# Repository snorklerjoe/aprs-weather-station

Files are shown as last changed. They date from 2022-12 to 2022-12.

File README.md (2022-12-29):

# aprs-weather-station
An APRS weather station with a transmitter designed from scratch

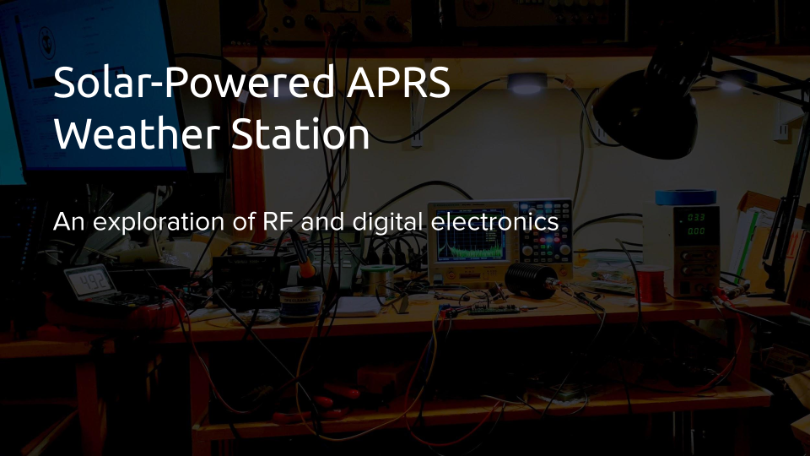
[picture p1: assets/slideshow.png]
Link to slideshow with more info (https://docs.google.com/presentation/d/e/2PACX-1vTTjzmcnAMqO2CPDlmQrg4AF5uw97dXVN1kHOskOywPoeaysDxAKATVa35npatWT-IwA0Ih-Vha_gMK/pub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)

_(Slideshow with more info)_

For more information, see my [blog](https://www.hosticlefifer.com/blog/?show=14)!

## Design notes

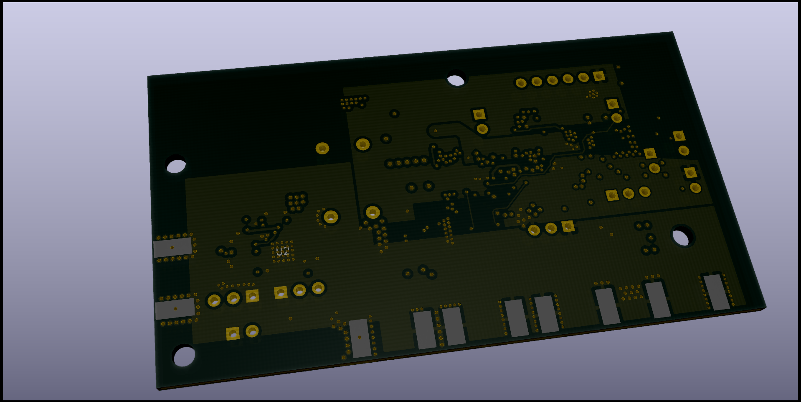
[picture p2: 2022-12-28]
hardware/radio/radio_back.png

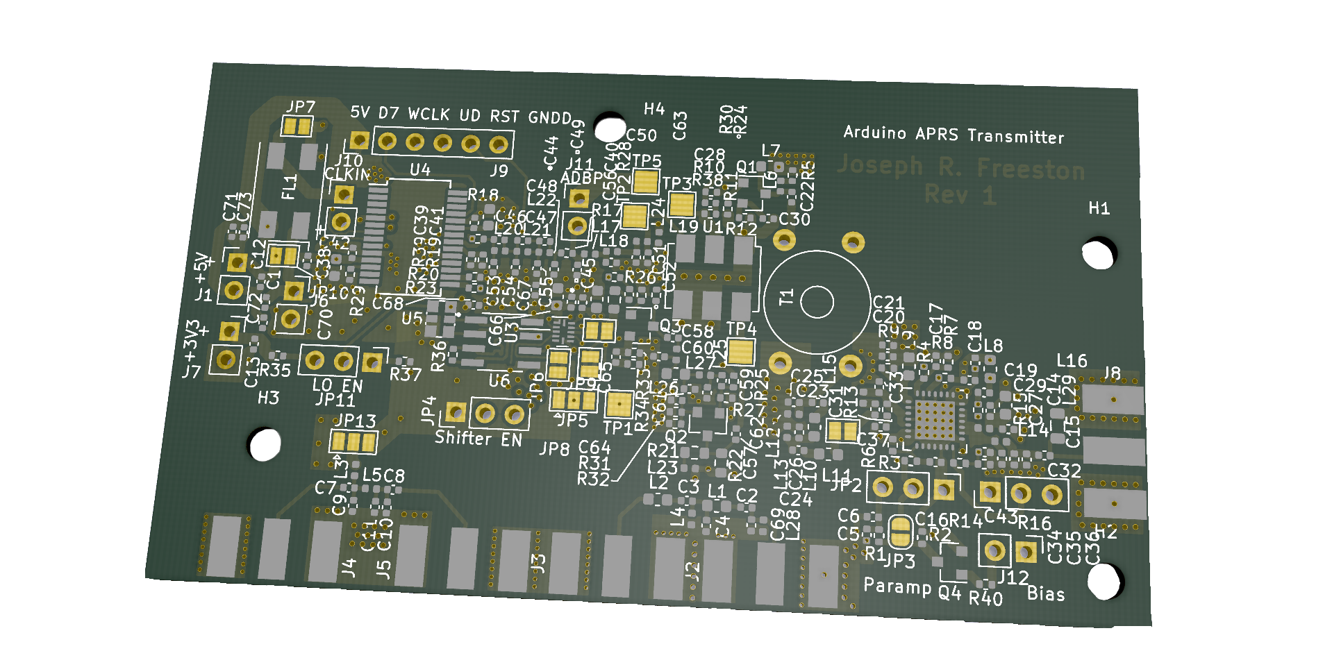
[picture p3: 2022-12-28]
hardware/radio/radio.png

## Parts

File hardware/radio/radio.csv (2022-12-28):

Source: | /home/joseph/projects/weather-station/radio/radio.sch
Date: | Wed 24 Nov 2021 07:50:49 PM EST
Tool: | Eeschema 5.1.12-84ad8e8a86~92~ubuntu20.04.1
Generator: | /usr/share/kicad/plugins/bom_csv_grouped_by_value.py
Component Count: | 165
Individual Components:
Item | Qty | Reference(s) | Value | LibPart | Footprint | Datasheet | Category | DK_Datasheet_Link | DK_Detail_Page | Description | Digi-Key_PN | Family | MPN | Manufacturer | Status
 |  | C1 | 10u | Device:C_Small |  | ~
 |  | C2 | 1p | Device:C_Small |  | ~
 |  | C3 | 1p | Device:C_Small |  | ~
 |  | C4 | 510p | Device:C_Small |  | ~
 |  | C5 | 1u | Device:C_Small |  | ~
 |  | C6 | 470p | Device:C_Small |  | ~
 |  | C7 | 2.5n | Device:C |  | ~
 |  | C8 | 470p | Device:C_Small |  | ~
 |  | C9 | 12p | Device:C_Small |  | ~
 |  | C10 | 56p | Device:C_Small |  | ~
 |  | C11 | 5.6p | Device:C_Small |  | ~
 |  | C12 | 10u | Device:C_Small |  | ~
 |  | C13 | 10u | Device:C_Small |  | ~
 |  | C14 | 4.7u | Device:C_Small |  | ~
 |  | C15 | 470p | Device:C_Small |  | ~
 |  | C16 | 10n | Device:C |  | ~
 |  | C17 | 10n | Device:C |  | ~
 |  | C18 | 470p | Device:C_Small |  | ~
 |  | C19 | 1u | Device:C_Small |  | ~
 |  | C20 | 1u | Device:C_Small |  | ~
 |  | C21 | 470p | Device:C_Small |  | ~
 |  | C22 | 2.5n | Device:C |  | ~
 |  | C23 | 1p | Device:C_Small |  | ~
 |  | C24 | 1p | Device:C_Small |  | ~
 |  | C25 | 510p | Device:C_Small |  | ~
 |  | C26 | 510p | Device:C_Small |  | ~
 |  | C27 | 1u | Device:C_Small |  | ~
 |  | C28 | 2.5n | Device:C |  | ~
 |  | C29 | C_Small | Device:C_Small |  | ~
 |  | C30 | 1n | Device:C_Small |  | ~
 |  | C31 | 470pF | Device:C_Small |  | ~
 |  | C32 | 470p | Device:C_Small |  | ~
 |  | C33 | 3.3pF | Device:C_Small |  | ~
 |  | C34 | 12p | Device:C_Small |  | ~
 |  | C35 | 56p | Device:C_Small |  | ~
 |  | C36 | 5.6p | Device:C_Small |  | ~
 |  | C37 | 1nF | Device:C_Small |  | ~
 |  | C38 | 10u | Device:C_Small |  | ~
 |  | C39 | 10u | Device:C_Small |  | ~
 |  | C40 | 10u | Device:C_Small |  | ~
 |  | C41 | 0.1u | Device:C_Small |  | ~
 |  | C42 | 0.1u | Device:C_Small |  | ~
 |  | C43 | 100p | Device:C |  | ~
 |  | C44 | 0.1u | Device:C_Small |  | ~
 |  | C45 | 0.1u | Device:C_Small |  | ~
 |  | C46 | 1p | Device:C_Small |  | ~
 |  | C47 | 5.6p | Device:C_Small |  | ~
 |  | C48 | 4.7p | Device:C_Small |  | ~
 |  | C49 | 1.5n | Device:C_Small |  | ~
 |  | C50 | 2n | Device:C_Small |  | ~
 |  | C51 | 2n | Device:C_Small |  | ~
 |  | C52 | 2n | Device:C_Small |  | ~
 |  | C53 | 22p | Device:C_Small |  | ~
 |  | C54 | 33p | Device:C_Small |  | ~
 |  | C55 | 22p | Device:C_Small |  | ~
 |  | C56 | 22p | Device:C_Small |  | ~
 |  | C57 | 2.5n | Device:C |  | ~
 |  | C58 | 2.5n | Device:C |  | ~
 |  | C59 | 2.5n | Device:C |  | ~
 |  | C60 | 36p | Device:C_Small |  | ~
 |  | C61 | 47p | Device:C_Small |  | ~
 |  | C62 | 13p | Device:C_Small |  | ~
 |  | C63 | 2.5n | Device:C |  | ~
 |  | C64 | 2.5n | Device:C_Small |  | ~
 |  | C65 | 100p | Device:C_Small |  | ~
 |  | C66 | 10u | Device:C_Small |  | ~
 |  | C67 | 0.1uF | Device:C_Small |  | ~
 |  | C68 | 0.1uF | Device:C_Small |  | ~
 |  | FL1 | EMI_Filter_CommonMode | Device:EMI_Filter_CommonMode |  | ~
 |  | J1 | +5VD | Connector:Conn_01x02_Male |  | ~
 |  | J2 | in | dk_Coaxial-Connectors-RF:142-0701-801 | digikey-footprints:RF_SMA_BoardEdge_142-0701-801 | http://www.belfuse.com/resources/Johnson/drawings/dr-1420701801.pdf | Connectors, Interconnects | http://www.belfuse.com/resources/Johnson/drawings/dr-1420701801.pdf | /product-detail/en/cinch-connectivity-solutions-johnson/142-0701-801/J502-ND/35280 | CONN SMA JACK STR 50OHM EDGE MNT | J502-ND | Coaxial Connectors (RF) | 142-0701-801 | Cinch Connectivity Solutions Johnson | Active
 |  | J3 | out | dk_Coaxial-Connectors-RF:142-0701-801 | digikey-footprints:RF_SMA_BoardEdge_142-0701-801 | http://www.belfuse.com/resources/Johnson/drawings/dr-1420701801.pdf | Connectors, Interconnects | http://www.belfuse.com/resources/Johnson/drawings/dr-1420701801.pdf | /product-detail/en/cinch-connectivity-solutions-johnson/142-0701-801/J502-ND/35280 | CONN SMA JACK STR 50OHM EDGE MNT | J502-ND | Coaxial Connectors (RF) | 142-0701-801 | Cinch Connectivity Solutions Johnson | Active
 |  | J4 | in | dk_Coaxial-Connectors-RF:142-0701-801 | digikey-footprints:RF_SMA_BoardEdge_142-0701-801 | http://www.belfuse.com/resources/Johnson/drawings/dr-1420701801.pdf | Connectors, Interconnects | http://www.belfuse.com/resources/Johnson/drawings/dr-1420701801.pdf | /product-detail/en/cinch-connectivity-solutions-johnson/142-0701-801/J502-ND/35280 | CONN SMA JACK STR 50OHM EDGE MNT | J502-ND | Coaxial Connectors (RF) | 142-0701-801 | Cinch Connectivity Solutions Johnson | Active
 |  | J5 | out | dk_Coaxial-Connectors-RF:142-0701-801 | digikey-footprints:RF_SMA_BoardEdge_142-0701-801 | http://www.belfuse.com/resources/Johnson/drawings/dr-1420701801.pdf | Connectors, Interconnects | http://www.belfuse.com/resources/Johnson/drawings/dr-1420701801.pdf | /product-detail/en/cinch-connectivity-solutions-johnson/142-0701-801/J502-ND/35280 | CONN SMA JACK STR 50OHM EDGE MNT | J502-ND | Coaxial Connectors (RF) | 142-0701-801 | Cinch Connectivity Solutions Johnson | Active
 |  | J6 | +5VA | Connector:Conn_01x02_Male |  | ~
 |  | J7 | +3VA | Connector:Conn_01x02_Male |  | ~
 |  | J8 | Antenna | dk_Coaxial-Connectors-RF:142-0701-801 | digikey-footprints:RF_SMA_BoardEdge_142-0701-801 | http://www.belfuse.com/resources/Johnson/drawings/dr-1420701801.pdf | Connectors, Interconnects | http://www.belfuse.com/resources/Johnson/drawings/dr-1420701801.pdf | /product-detail/en/cinch-connectivity-solutions-johnson/142-0701-801/J502-ND/35280 | CONN SMA JACK STR 50OHM EDGE MNT | J502-ND | Coaxial Connectors (RF) | 142-0701-801 | Cinch Connectivity Solutions Johnson | Active
 |  | J9 | FREQ CTRL | Connector:Conn_01x06_Male |  | ~
 |  | J10 | CLK_125MHz | Connector:Conn_01x02_Male |  | ~
 |  | J11 | 50 Ohm IF IN | Connector:Conn_01x02_Male |  | ~
 |  | JP1 | Vbias | Device:Jumper_NC_Dual |  | ~
 |  | JP2 | Vparamp | Device:Jumper_NC_Dual |  | ~
 |  | JP3 | paramp en | Jumper:SolderJumper_2_Open |  | ~
 |  | JP4 | DDS Clock EN | Device:Jumper_NC_Dual |  | ~
 |  | JP5 | Shift LO | Jumper:SolderJumper_3_Bridged12 |  | ~
 |  | JP6 | A3 | Jumper:SolderJumper_2_Bridged |  | ~
 |  | JP7 | choke bp | Jumper:SolderJumper_2_Open |  | ~
 |  | JP8 | 5V LO | Jumper:SolderJumper_2_Open |  | ~
 |  | JP9 | 3V LO | Jumper:SolderJumper_2_Bridged |  | ~
 |  | JP10 | choke bp | Jumper:SolderJumper_2_Open |  | ~
 |  | JP11 | Jumper_NC_Dual | Device:Jumper_NC_Dual |  | ~
 |  | L1 | 1.2u | Device:L |  | ~
 |  | L2 | 1.2u | Device:L |  | ~
 |  | L3 | 19n | Device:L |  | ~
 |  | L4 | 2.4n | Device:L |  | ~
 |  | L5 | 12n | Device:L |  | ~
 |  | L6 | 0.1u | Device:L |  | 0630CS
 |  | L7 | 5u | Device:L |  | 0630CS
 |  | L8 | 56n | Device:L |  | ~
 |  | L9 | 56n | Device:L |  | ~
 |  | L10 | 1.2u | Device:L |  | ~
 |  | L11 | 1.2u | Device:L |  | ~
 |  | L12 | 2.4n | Device:L |  | ~
 |  | L13 | 2.4n | Device:L |  | ~
 |  | L14 | 19n | Device:L |  | ~
 |  | L15 | 150nH | Device:L |  | 0630CS
 |  | L16 | 12n | Device:L |  | ~
 |  | L17 | 120n | Device:L |  | ~
 |  | L18 | 130n | Device:L |  | ~
 |  | L19 | 120n | Device:L |  | ~
 |  | L20 | 470n | Device:L |  | ~
 |  | L21 | 390n | Device:L |  | ~
 |  | L22 | 390n | Device:L |  | ~
 |  | L23 | 10u | Device:L |  | ~
 |  | L24 | 10u | Device:L |  | ~
 |  | L25 | 33n | Device:L |  | ~
 |  | L26 | 123n | Device:L |  | ~
 |  | L27 | 90n | Device:L |  | ~
 |  | Q1 | MMBTH10 | Device:Q_NPN_BEC |  | ~
 |  | Q2 | 2N2222 | Device:Q_NPN_BEC |  | ~
 |  | Q3 | 2N2222 | Device:Q_NPN_BEC |  | ~
 |  | R1 | 1k | Device:R |  | ~
 |  | R2 | 1k | Device:R |  | ~
 |  | R3 | 68k | Device:R |  | ~
 |  | R4 | 68k | Device:R |  | ~
 |  | R5 | 51 | Device:R |  | ~
 |  | R6 | 68k | Device:R |  | ~
 |  | R7 | 47k | Device:R |  | ~
 |  | R8 | R | Device:R |  | ~
 |  | R9 | R | Device:R |  | ~
 |  | R10 | 470 | Device:R |  | ~
 |  | R11 | 510 | Device:R |  | ~
 |  | R12 | 68 | Device:R |  | ~
 |  | R13 | 680 | Device:R |  | ~
 |  | R14 | 100k | Device:R |  | ~
 |  | R15 | 51 | Device:R |  | ~
 |  | R16 | 39k | Device:R |  | ~
 |  | R17 | 0 | Device:R |  | ~
 |  | R18 | 50 | Device:R |  | ~
 |  | R19 | 25 | Device:R |  | ~
 |  | R20 | 1k | Device:R |  | ~
 |  | R21 | 30 | Device:R |  | ~
 |  | R22 | 75 | Device:R |  | ~
 |  | R23 | 1k | Device:R |  | ~
 |  | R24 | 150 | Device:R |  | ~
 |  | R25 | 1.2k | Device:R |  | ~
 |  | R26 | 2k | Device:R |  | ~
 |  | R27 | 1.2k | Device:R |  | ~
 |  | R28 | 75 | Device:R |  | ~
 |  | R29 | 3.9k | Device:R |  | ~
 |  | R30 | 1.2k | Device:R |  | ~
 |  | R31 | 47 | Device:R |  | ~
 |  | R32 | 47 | Device:R |  | ~
 |  | R33 | 100 | Device:R |  | ~
 |  | R34 | 10 | Device:R |  | ~
 |  | R35 | 1k | Device:R |  | ~
 |  | R36 | 100 | Device:R |  | ~
 |  | R37 | 1k | Device:R |  | ~
 |  | T1 | Transformer_1P_1S | Device:Transformer_1P_1S |  | ~
 |  | U1 | ADE-11X+ | dk_RF-Demodulators:ADE-11X+ | RF_Mini-Circuits:Mini-Circuits_CD542_LandPatternPL-052 | www.minicircuits.com/pdfs/ADE-6.pdf
 |  | U2 | CMX901 | dk_RF-Amplifiers:CMX901 | Home:QFN-28_EP_5x5_Pitch0.5mm | CMX901QT8
 |  | U3 | TXU0304RUTR | dk_Logic-Translators-Level-Shifters:TXU0304RUTR | Package_DFN_QFN:Texas_R_PUQFN-N12 | http://www.ti.com/lit/ds/symlink/txu0104.pdf
 |  | U4 | AD9850 | Interface:AD9850 | Package_SO:SSOP-28_5.3x10.2mm_P0.65mm | https://www.analog.com/media/en/technical-documentation/data-sheets/AD9850.pdf
 |  | U5 | SiT9365AC-2B1-33E | dk_Oscillators:SiT9365AC-2B1-33E | Home:POD-038-PQFD-006-C03225
 |  | U6 | DS90LV028ATM | DS90LV028ATM:DS90LV028ATM | SOIC127P599X175-8N
Collated Components:
Item | Qty | Reference(s) | Value | LibPart | Footprint | Datasheet | Category | DK_Datasheet_Link | DK_Detail_Page | Description | Digi-Key_PN | Family | MPN | Manufacturer | Status
1 | 7 | C1, C12, C13, C38, C39, C40, C66 | 10u | Device:C_Small |  | ~
2 | 5 | C2, C3, C23, C24, C46 | 1p | Device:C_Small |  | ~
3 | 3 | C4, C25, C26 | 510p | Device:C_Small |  | ~
4 | 4 | C5, C19, C20, C27 | 1u | Device:C_Small |  | ~
5 | 6 | C6, C8, C15, C18, C21, C32 | 470p | Device:C_Small |  | ~
6 | 7 | C7, C22, C28, C57, C58, C59, C63 | 2.5n | Device:C |  | ~
7 | 2 | C9, C34 | 12p | Device:C_Small |  | ~
8 | 2 | C10, C35 | 56p | Device:C_Small |  | ~
9 | 3 | C11, C36, C47 | 5.6p | Device:C_Small |  | ~
10 | 1 | C14 | 4.7u | Device:C_Small |  | ~
11 | 2 | C16, C17 | 10n | Device:C |  | ~
12 | 1 | C29 | C_Small | Device:C_Small |  | ~
13 | 1 | C30 | 1n | Device:C_Small |  | ~
14 | 1 | C31 | 470pF | Device:C_Small |  | ~
15 | 1 | C33 | 3.3pF | Device:C_Small |  | ~
16 | 1 | C37 | 1nF | Device:C_Small |  | ~
17 | 4 | C41, C42, C44, C45 | 0.1u | Device:C_Small |  | ~
18 | 1 | C43 | 100p | Device:C |  | ~
19 | 1 | C48 | 4.7p | Device:C_Small |  | ~
20 | 1 | C49 | 1.5n | Device:C_Small |  | ~
21 | 3 | C50, C51, C52 | 2n | Device:C_Small |  | ~
22 | 3 | C53, C55, C56 | 22p | Device:C_Small |  | ~
23 | 1 | C54 | 33p | Device:C_Small |  | ~
24 | 1 | C60 | 36p | Device:C_Small |  | ~
25 | 1 | C61 | 47p | Device:C_Small |  | ~
26 | 1 | C62 | 13p | Device:C_Small |  | ~
27 | 1 | C64 | 2.5n | Device:C_Small |  | ~
28 | 1 | C65 | 100p | Device:C_Small |  | ~
29 | 2 | C67, C68 | 0.1uF | Device:C_Small |  | ~
30 | 1 | FL1 | EMI_Filter_CommonMode | Device:EMI_Filter_CommonMode |  | ~
31 | 1 | J1 | +5VD | Connector:Conn_01x02_Male |  | ~
32 | 2 | J2, J4 | in | dk_Coaxial-Connectors-RF:142-0701-801 | digikey-footprints:RF_SMA_BoardEdge_142-0701-801 | http://www.belfuse.com/resources/Johnson/drawings/dr-1420701801.pdf | Connectors, Interconnects | http://www.belfuse.com/resources/Johnson/drawings/dr-1420701801.pdf | /product-detail/en/cinch-connectivity-solutions-johnson/142-0701-801/J502-ND/35280 | CONN SMA JACK STR 50OHM EDGE MNT | J502-ND | Coaxial Connectors (RF) | 142-0701-801 | Cinch Connectivity Solutions Johnson | Active
33 | 2 | J3, J5 | out | dk_Coaxial-Connectors-RF:142-0701-801 | digikey-footprints:RF_SMA_BoardEdge_142-0701-801 | http://www.belfuse.com/resources/Johnson/drawings/dr-1420701801.pdf | Connectors, Interconnects | http://www.belfuse.com/resources/Johnson/drawings/dr-1420701801.pdf | /product-detail/en/cinch-connectivity-solutions-johnson/142-0701-801/J502-ND/35280 | CONN SMA JACK STR 50OHM EDGE MNT | J502-ND | Coaxial Connectors (RF) | 142-0701-801 | Cinch Connectivity Solutions Johnson | Active
34 | 1 | J6 | +5VA | Connector:Conn_01x02_Male |  | ~
35 | 1 | J7 | +3VA | Connector:Conn_01x02_Male |  | ~
36 | 1 | J8 | Antenna | dk_Coaxial-Connectors-RF:142-0701-801 | digikey-footprints:RF_SMA_BoardEdge_142-0701-801 | http://www.belfuse.com/resources/Johnson/drawings/dr-1420701801.pdf | Connectors, Interconnects | http://www.belfuse.com/resources/Johnson/drawings/dr-1420701801.pdf | /product-detail/en/cinch-connectivity-solutions-johnson/142-0701-801/J502-ND/35280 | CONN SMA JACK STR 50OHM EDGE MNT | J502-ND | Coaxial Connectors (RF) | 142-0701-801 | Cinch Connectivity Solutions Johnson | Active
37 | 1 | J9 | FREQ CTRL | Connector:Conn_01x06_Male |  | ~
38 | 1 | J10 | CLK_125MHz | Connector:Conn_01x02_Male |  | ~
39 | 1 | J11 | 50 Ohm IF IN | Connector:Conn_01x02_Male |  | ~
40 | 1 | JP1 | Vbias | Device:Jumper_NC_Dual |  | ~
41 | 1 | JP2 | Vparamp | Device:Jumper_NC_Dual |  | ~
42 | 1 | JP3 | paramp en | Jumper:SolderJumper_2_Open |  | ~
43 | 1 | JP4 | DDS Clock EN | Device:Jumper_NC_Dual |  | ~
44 | 1 | JP5 | Shift LO | Jumper:SolderJumper_3_Bridged12 |  | ~
45 | 1 | JP6 | A3 | Jumper:SolderJumper_2_Bridged |  | ~
46 | 2 | JP7, JP10 | choke bp | Jumper:SolderJumper_2_Open |  | ~
47 | 1 | JP8 | 5V LO | Jumper:SolderJumper_2_Open |  | ~
48 | 1 | JP9 | 3V LO | Jumper:SolderJumper_2_Bridged |  | ~
49 | 1 | JP11 | Jumper_NC_Dual | Device:Jumper_NC_Dual |  | ~
50 | 4 | L1, L2, L10, L11 | 1.2u | Device:L |  | ~
51 | 2 | L3, L14 | 19n | Device:L |  | ~
52 | 3 | L4, L12, L13 | 2.4n | Device:L |  | ~
53 | 2 | L5, L16 | 12n | Device:L |  | ~
54 | 1 | L6 | 0.1u | Device:L |  | 0630CS
55 | 1 | L7 | 5u | Device:L |  | 0630CS
56 | 2 | L8, L9 | 56n | Device:L |  | ~
57 | 1 | L15 | 150nH | Device:L |  | 0630CS
58 | 2 | L17, L19 | 120n | Device:L |  | ~
59 | 1 | L18 | 130n | Device:L |  | ~
60 | 1 | L20 | 470n | Device:L |  | ~
61 | 2 | L21, L22 | 390n | Device:L |  | ~
62 | 2 | L23, L24 | 10u | Device:L |  | ~
63 | 1 | L25 | 33n | Device:L |  | ~
64 | 1 | L26 | 123n | Device:L |  | ~
65 | 1 | L27 | 90n | Device:L |  | ~
66 | 1 | Q1 | MMBTH10 | Device:Q_NPN_BEC |  | ~
67 | 2 | Q2, Q3 | 2N2222 | Device:Q_NPN_BEC |  | ~
68 | 6 | R1, R2, R20, R23, R35, R37 | 1k | Device:R |  | ~
69 | 3 | R3, R4, R6 | 68k | Device:R |  | ~
70 | 2 | R5, R15 | 51 | Device:R |  | ~
71 | 1 | R7 | 47k | Device:R |  | ~
72 | 2 | R8, R9 | R | Device:R |  | ~
73 | 1 | R10 | 470 | Device:R |  | ~
74 | 1 | R11 | 510 | Device:R |  | ~
75 | 1 | R12 | 68 | Device:R |  | ~
76 | 1 | R13 | 680 | Device:R |  | ~
77 | 1 | R14 | 100k | Device:R |  | ~
78 | 1 | R16 | 39k | Device:R |  | ~
79 | 1 | R17 | 0 | Device:R |  | ~
80 | 1 | R18 | 50 | Device:R |  | ~
81 | 1 | R19 | 25 | Device:R |  | ~
82 | 1 | R21 | 30 | Device:R |  | ~
83 | 2 | R22, R28 | 75 | Device:R |  | ~
84 | 1 | R24 | 150 | Device:R |  | ~
85 | 3 | R25, R27, R30 | 1.2k | Device:R |  | ~
86 | 1 | R26 | 2k | Device:R |  | ~
87 | 1 | R29 | 3.9k | Device:R |  | ~
88 | 2 | R31, R32 | 47 | Device:R |  | ~
89 | 2 | R33, R36 | 100 | Device:R |  | ~
90 | 1 | R34 | 10 | Device:R |  | ~
91 | 1 | T1 | Transformer_1P_1S | Device:Transformer_1P_1S |  | ~
92 | 1 | U1 | ADE-11X+ | dk_RF-Demodulators:ADE-11X+ | RF_Mini-Circuits:Mini-Circuits_CD542_LandPatternPL-052 | www.minicircuits.com/pdfs/ADE-6.pdf
93 | 1 | U2 | CMX901 | dk_RF-Amplifiers:CMX901 | Home:QFN-28_EP_5x5_Pitch0.5mm | CMX901QT8
94 | 1 | U3 | TXU0304RUTR | dk_Logic-Translators-Level-Shifters:TXU0304RUTR | Package_DFN_QFN:Texas_R_PUQFN-N12 | http://www.ti.com/lit/ds/symlink/txu0104.pdf
95 | 1 | U4 | AD9850 | Interface:AD9850 | Package_SO:SSOP-28_5.3x10.2mm_P0.65mm | https://www.analog.com/media/en/technical-documentation/data-sheets/AD9850.pdf
96 | 1 | U5 | SiT9365AC-2B1-33E | dk_Oscillators:SiT9365AC-2B1-33E | Home:POD-038-PQFD-006-C03225
97 | 1 | U6 | DS90LV028ATM | DS90LV028ATM:DS90LV028ATM | SOIC127P599X175-8N

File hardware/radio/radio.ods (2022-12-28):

Source: | /home/joseph/projects/weather-station/radio/radio.sch
Date: | Wed 24 Nov 2021 07:50:49 PM EST
Tool: | Eeschema 5.1.12-84ad8e8a86~92~ubuntu20.04.1
Generator: | /usr/share/kicad/plugins/bom_csv_grouped_by_value.py
Component Count: | 165
Individual Components:
Item | Qty | Reference(s) | Value | LibPart | Footprint | Datasheet | Category | DK_Datasheet_Link | DK_Detail_Page | Description | Digi-Key_PN | Family | MPN | Manufacturer | Status
 |  | C1 | 10u | Device:C_Small |  | ~
 |  | C2 | 1p | Device:C_Small |  | ~
 |  | C3 | 1p | Device:C_Small |  | ~
 |  | C4 | 510p | Device:C_Small |  | ~
 |  | C5 | 1u | Device:C_Small |  | ~
 |  | C6 | 470p | Device:C_Small |  | ~
 |  | C7 | 2.5n | Device:C |  | ~
 |  | C8 | 470p | Device:C_Small |  | ~
 |  | C9 | 12p | Device:C_Small |  | ~
 |  | C10 | 56p | Device:C_Small |  | ~
 |  | C11 | 5.6p | Device:C_Small |  | ~
 |  | C12 | 10u | Device:C_Small |  | ~
 |  | C13 | 10u | Device:C_Small |  | ~
 |  | C14 | 4.7u | Device:C_Small |  | ~
 |  | C15 | 470p | Device:C_Small |  | ~
 |  | C16 | 10n | Device:C |  | ~
 |  | C17 | 10n | Device:C |  | ~
 |  | C18 | 470p | Device:C_Small |  | ~
 |  | C19 | 1u | Device:C_Small |  | ~
 |  | C20 | 1u | Device:C_Small |  | ~
 |  | C21 | 470p | Device:C_Small |  | ~
 |  | C22 | 2.5n | Device:C |  | ~
 |  | C23 | 1p | Device:C_Small |  | ~
 |  | C24 | 1p | Device:C_Small |  | ~
 |  | C25 | 510p | Device:C_Small |  | ~
 |  | C26 | 510p | Device:C_Small |  | ~
 |  | C27 | 1u | Device:C_Small |  | ~
 |  | C28 | 2.5n | Device:C |  | ~
 |  | C29 | C_Small | Device:C_Small |  | ~
 |  | C30 | 1n | Device:C_Small |  | ~
 |  | C31 | 470pF | Device:C_Small |  | ~
 |  | C32 | 470p | Device:C_Small |  | ~
 |  | C33 | 3.3pF | Device:C_Small |  | ~
 |  | C34 | 12p | Device:C_Small |  | ~
 |  | C35 | 56p | Device:C_Small |  | ~
 |  | C36 | 5.6p | Device:C_Small |  | ~
 |  | C37 | 1nF | Device:C_Small |  | ~
 |  | C38 | 10u | Device:C_Small |  | ~
 |  | C39 | 10u | Device:C_Small |  | ~
 |  | C40 | 10u | Device:C_Small |  | ~
 |  | C41 | 0.1u | Device:C_Small |  | ~
 |  | C42 | 0.1u | Device:C_Small |  | ~
 |  | C43 | 100p | Device:C |  | ~
 |  | C44 | 0.1u | Device:C_Small |  | ~
 |  | C45 | 0.1u | Device:C_Small |  | ~
 |  | C46 | 1p | Device:C_Small |  | ~
 |  | C47 | 5.6p | Device:C_Small |  | ~
 |  | C48 | 4.7p | Device:C_Small |  | ~
 |  | C49 | 1.5n | Device:C_Small |  | ~
 |  | C50 | 2n | Device:C_Small |  | ~
 |  | C51 | 2n | Device:C_Small |  | ~
 |  | C52 | 2n | Device:C_Small |  | ~
 |  | C53 | 22p | Device:C_Small |  | ~
 |  | C54 | 33p | Device:C_Small |  | ~
 |  | C55 | 22p | Device:C_Small |  | ~
 |  | C56 | 22p | Device:C_Small |  | ~
 |  | C57 | 2.5n | Device:C |  | ~
 |  | C58 | 2.5n | Device:C |  | ~
 |  | C59 | 2.5n | Device:C |  | ~
 |  | C60 | 36p | Device:C_Small |  | ~
 |  | C61 | 47p | Device:C_Small |  | ~
 |  | C62 | 13p | Device:C_Small |  | ~
 |  | C63 | 2.5n | Device:C |  | ~
 |  | C64 | 2.5n | Device:C_Small |  | ~
 |  | C65 | 100p | Device:C_Small |  | ~
 |  | C66 | 10u | Device:C_Small |  | ~
 |  | C67 | 0.1uF | Device:C_Small |  | ~
 |  | C68 | 0.1uF | Device:C_Small |  | ~
 |  | FL1 | EMI_Filter_CommonMode | Device:EMI_Filter_CommonMode |  | ~
 |  | J1 | +5VD | Connector:Conn_01x02_Male |  | ~
 |  | J2 | in | dk_Coaxial-Connectors-RF:142-0701-801 | digikey-footprints:RF_SMA_BoardEdge_142-0701-801 | http://www.belfuse.com/resources/Johnson/drawings/dr-1420701801.pdf | Connectors, Interconnects | http://www.belfuse.com/resources/Johnson/drawings/dr-1420701801.pdf | /product-detail/en/cinch-connectivity-solutions-johnson/142-0701-801/J502-ND/35280 | CONN SMA JACK STR 50OHM EDGE MNT | J502-ND | Coaxial Connectors (RF) | 142-0701-801 | Cinch Connectivity Solutions Johnson | Active
 |  | J3 | out | dk_Coaxial-Connectors-RF:142-0701-801 | digikey-footprints:RF_SMA_BoardEdge_142-0701-801 | http://www.belfuse.com/resources/Johnson/drawings/dr-1420701801.pdf | Connectors, Interconnects | http://www.belfuse.com/resources/Johnson/drawings/dr-1420701801.pdf | /product-detail/en/cinch-connectivity-solutions-johnson/142-0701-801/J502-ND/35280 | CONN SMA JACK STR 50OHM EDGE MNT | J502-ND | Coaxial Connectors (RF) | 142-0701-801 | Cinch Connectivity Solutions Johnson | Active
 |  | J4 | in | dk_Coaxial-Connectors-RF:142-0701-801 | digikey-footprints:RF_SMA_BoardEdge_142-0701-801 | http://www.belfuse.com/resources/Johnson/drawings/dr-1420701801.pdf | Connectors, Interconnects | http://www.belfuse.com/resources/Johnson/drawings/dr-1420701801.pdf | /product-detail/en/cinch-connectivity-solutions-johnson/142-0701-801/J502-ND/35280 | CONN SMA JACK STR 50OHM EDGE MNT | J502-ND | Coaxial Connectors (RF) | 142-0701-801 | Cinch Connectivity Solutions Johnson | Active
 |  | J5 | out | dk_Coaxial-Connectors-RF:142-0701-801 | digikey-footprints:RF_SMA_BoardEdge_142-0701-801 | http://www.belfuse.com/resources/Johnson/drawings/dr-1420701801.pdf | Connectors, Interconnects | http://www.belfuse.com/resources/Johnson/drawings/dr-1420701801.pdf | /product-detail/en/cinch-connectivity-solutions-johnson/142-0701-801/J502-ND/35280 | CONN SMA JACK STR 50OHM EDGE MNT | J502-ND | Coaxial Connectors (RF) | 142-0701-801 | Cinch Connectivity Solutions Johnson | Active
 |  | J6 | +5VA | Connector:Conn_01x02_Male |  | ~
 |  | J7 | +3VA | Connector:Conn_01x02_Male |  | ~
 |  | J8 | Antenna | dk_Coaxial-Connectors-RF:142-0701-801 | digikey-footprints:RF_SMA_BoardEdge_142-0701-801 | http://www.belfuse.com/resources/Johnson/drawings/dr-1420701801.pdf | Connectors, Interconnects | http://www.belfuse.com/resources/Johnson/drawings/dr-1420701801.pdf | /product-detail/en/cinch-connectivity-solutions-johnson/142-0701-801/J502-ND/35280 | CONN SMA JACK STR 50OHM EDGE MNT | J502-ND | Coaxial Connectors (RF) | 142-0701-801 | Cinch Connectivity Solutions Johnson | Active
 |  | J9 | FREQ CTRL | Connector:Conn_01x06_Male |  | ~
 |  | J10 | CLK_125MHz | Connector:Conn_01x02_Male |  | ~
 |  | J11 | 50 Ohm IF IN | Connector:Conn_01x02_Male |  | ~
 |  | JP1 | Vbias | Device:Jumper_NC_Dual |  | ~
 |  | JP2 | Vparamp | Device:Jumper_NC_Dual |  | ~
 |  | JP3 | paramp en | Jumper:SolderJumper_2_Open |  | ~
 |  | JP4 | DDS Clock EN | Device:Jumper_NC_Dual |  | ~
 |  | JP5 | Shift LO | Jumper:SolderJumper_3_Bridged12 |  | ~
 |  | JP6 | A3 | Jumper:SolderJumper_2_Bridged |  | ~
 |  | JP7 | choke bp | Jumper:SolderJumper_2_Open |  | ~
 |  | JP8 | 5V LO | Jumper:SolderJumper_2_Open |  | ~
 |  | JP9 | 3V LO | Jumper:SolderJumper_2_Bridged |  | ~
 |  | JP10 | choke bp | Jumper:SolderJumper_2_Open |  | ~
 |  | JP11 | Jumper_NC_Dual | Device:Jumper_NC_Dual |  | ~
 |  | L1 | 1.2u | Device:L |  | ~
 |  | L2 | 1.2u | Device:L |  | ~
 |  | L3 | 19n | Device:L |  | ~
 |  | L4 | 2.4n | Device:L |  | ~
 |  | L5 | 12n | Device:L |  | ~
 |  | L6 | 0.1u | Device:L |  | 0630CS
 |  | L7 | 5u | Device:L |  | 0630CS
 |  | L8 | 56n | Device:L |  | ~
 |  | L9 | 56n | Device:L |  | ~
 |  | L10 | 1.2u | Device:L |  | ~
 |  | L11 | 1.2u | Device:L |  | ~
 |  | L12 | 2.4n | Device:L |  | ~
 |  | L13 | 2.4n | Device:L |  | ~
 |  | L14 | 19n | Device:L |  | ~
 |  | L15 | 150nH | Device:L |  | 0630CS
 |  | L16 | 12n | Device:L |  | ~
 |  | L17 | 120n | Device:L |  | ~
 |  | L18 | 130n | Device:L |  | ~
 |  | L19 | 120n | Device:L |  | ~
 |  | L20 | 470n | Device:L |  | ~
 |  | L21 | 390n | Device:L |  | ~
 |  | L22 | 390n | Device:L |  | ~
 |  | L23 | 10u | Device:L |  | ~
 |  | L24 | 10u | Device:L |  | ~
 |  | L25 | 33n | Device:L |  | ~
 |  | L26 | 123n | Device:L |  | ~
 |  | L27 | 90n | Device:L |  | ~
 |  | Q1 | MMBTH10 | Device:Q_NPN_BEC |  | ~
 |  | Q2 | 2N2222 | Device:Q_NPN_BEC |  | ~
 |  | Q3 | 2N2222 | Device:Q_NPN_BEC |  | ~
 |  | R1 | 1k | Device:R |  | ~
 |  | R2 | 1k | Device:R |  | ~
 |  | R3 | 68k | Device:R |  | ~
 |  | R4 | 68k | Device:R |  | ~
 |  | R5 | 51 | Device:R |  | ~
 |  | R6 | 68k | Device:R |  | ~
 |  | R7 | 47k | Device:R |  | ~
 |  | R8 | R | Device:R |  | ~
 |  | R9 | R | Device:R |  | ~
 |  | R10 | 470 | Device:R |  | ~
 |  | R11 | 510 | Device:R |  | ~
 |  | R12 | 68 | Device:R |  | ~
 |  | R13 | 680 | Device:R |  | ~
 |  | R14 | 100k | Device:R |  | ~
 |  | R15 | 51 | Device:R |  | ~
 |  | R16 | 39k | Device:R |  | ~
 |  | R17 | 0 | Device:R |  | ~
 |  | R18 | 50 | Device:R |  | ~
 |  | R19 | 25 | Device:R |  | ~
 |  | R20 | 1k | Device:R |  | ~
 |  | R21 | 30 | Device:R |  | ~
 |  | R22 | 75 | Device:R |  | ~
 |  | R23 | 1k | Device:R |  | ~
 |  | R24 | 150 | Device:R |  | ~
 |  | R25 | 1.2k | Device:R |  | ~
 |  | R26 | 2k | Device:R |  | ~
 |  | R27 | 1.2k | Device:R |  | ~
 |  | R28 | 75 | Device:R |  | ~
 |  | R29 | 3.9k | Device:R |  | ~
 |  | R30 | 1.2k | Device:R |  | ~
 |  | R31 | 47 | Device:R |  | ~
 |  | R32 | 47 | Device:R |  | ~
 |  | R33 | 100 | Device:R |  | ~
 |  | R34 | 10 | Device:R |  | ~
 |  | R35 | 1k | Device:R |  | ~
 |  | R36 | 100 | Device:R |  | ~
 |  | R37 | 1k | Device:R |  | ~
 |  | T1 | Transformer_1P_1S | Device:Transformer_1P_1S |  | ~
 |  | U1 | ADE-11X+ | dk_RF-Demodulators:ADE-11X+ | RF_Mini-Circuits:Mini-Circuits_CD542_LandPatternPL-052 | www.minicircuits.com/pdfs/ADE-6.pdf
 |  | U2 | CMX901 | dk_RF-Amplifiers:CMX901 | Home:QFN-28_EP_5x5_Pitch0.5mm | CMX901QT8
 |  | U3 | TXU0304RUTR | dk_Logic-Translators-Level-Shifters:TXU0304RUTR | Package_DFN_QFN:Texas_R_PUQFN-N12 | http://www.ti.com/lit/ds/symlink/txu0104.pdf
 |  | U4 | AD9850 | Interface:AD9850 | Package_SO:SSOP-28_5.3x10.2mm_P0.65mm | https://www.analog.com/media/en/technical-documentation/data-sheets/AD9850.pdf
 |  | U5 | SiT9365AC-2B1-33E | dk_Oscillators:SiT9365AC-2B1-33E | Home:POD-038-PQFD-006-C03225
 |  | U6 | DS90LV028ATM | DS90LV028ATM:DS90LV028ATM | SOIC127P599X175-8N
Collated Components:
Item | Qty | Reference(s) | Value | LibPart | Footprint | Datasheet | Category | DK_Datasheet_Link | DK_Detail_Page | Description | Digi-Key_PN | Family | MPN | Manufacturer | Status
1 | 7 | C1, C12, C13, C38, C39, C40, C66 | 10u | ‎1276-1451-1-ND‎ (https://www.digikey.com/product-detail/en/CL05A106MQ5NUNC/1276-1451-1-ND/3889537?itemSeq=383434846) |  | ~
2 | 5 | C2, C3, C23, C24, C46 | 1p | 1276-1595-1-ND‎ (https://www.digikey.com/product-detail/en/CL05C010CB5NNNC/1276-1595-1-ND/3889681?itemSeq=383326518) |  | ~ |  |  |  |  | 1276-1595-1-ND‎ (https://www.digikey.com/product-detail/en/CL05C010CB5NNNC/1276-1595-1-ND/3889681?itemSeq=383326518)
3 | 4 | C4, C25, C26 | 510p | ‎1292-1332-1-ND‎ (https://www.digikey.com/product-detail/en/0402N511J500CT/1292-1332-1-ND/9355336?itemSeq=383326836) |  | ~
4 | 4 | C5, C19, C20, C27 | 1u | CL05A105KO5NNNC
5 | 7 | C6, C8, C15, C18, C21, C31, C32 | 470p | C0402X7R500-471KNP-CT
6 | 7 | C7, C22, C28, C57, C58, C59, C63 | 2.5n | X7R?
7 | 2 | C9, C34 | 12p | CL05C120JB51PNC
8 | 2 | C10, C35 | 56p | ‎311-1022-1-ND‎
9 | 3 | C11, C36, C47 | 5.6p | ‎399-C0402C569J5GAC7867CT-ND‎
10 | 1 | C14 | 4.7u | 1276-6836-1-ND‎ (https://www.digikey.com/product-detail/en/CL05A475MO5NUNC/1276-6836-1-ND/5961695?itemSeq=383412672) |  | ~
11 | 2 | C16, C17 | 10n | 0402B103J250CT |  | ~
12 | 1 | C29 | C_Small | Device:C_Small |  | ~
13 | 1 | C30, C37 | 1n | 0402N102J250CT
14
15 | 1 | C33 | 3.3p | ‎587-5130-1-ND‎ (https://www.digikey.com/product-detail/en/UVK105CG3R3JW-F/587-5130-1-ND/6576549?itemSeq=383408924)
16 |  |  |  |  |  | ~
17 | 6 | C41, C42, C44, C45, C67, C68 | 0.1u | 13-CC0402JRX7R8BB104CT-ND‎ (https://www.digikey.com/product-detail/en/CC0402JRX7R8BB104/13-CC0402JRX7R8BB104CT-ND/13889474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) |  | ~
18 | 1 | C43 | 100p | ‎1276-1025-1-ND‎ (https://www.digikey.com/product-detail/en/CL05C101JB5NNNC/1276-1025-1-ND/3889111?itemSeq=383409581) |  | ~
19 | 1 | C48 | 4.7p | UVK105CG4R7JW-F
20 | 1 | C49 | 1.5n | ‎399-14424-1-ND‎ (https://www.digikey.com/product-detail/en/C0402C152J5GAC7867/399-14424-1-ND/7103716?itemSeq=383411033)
21 | 3 | C50, C51, C52 | 2n | C0402C202J3GACAUTO
22 | 3 | C53, C55, C56 | 22p | ‎399-C0402C220J5GAC7411CT-ND‎ (https://www.digikey.com/product-detail/en/C0402C220J5GAC7411/399-C0402C220J5GAC7411CT-ND/12702002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)
23 | 1 | C54 | 33p | ‎1276-1272-1-ND‎ (https://www.digikey.com/product-detail/en/CL05C330JB5NNNC/1276-1272-1-ND/3889358?itemSeq=383409393)
24 | 1 | C60 | 36p | 0402N360J500CT
25 | 1 | C61 | 47p | ‎445-5592-1-ND‎ (https://www.digikey.com/product-detail/en/CGA2B2C0G1H470J050BA/445-5592-1-ND/2443632?itemSeq=383411792) |  | ~
26 | 1 | C62 | 13p | CC0402JRNPO9BN130 |  | ~
27 | 1 | C64 | 2.5n | Device:C_Small |  | ~
28 | 1 | C65 | 100p | Device:C_Small |  | ~
29 |  |  |  |  |  | ~
30 | 1 | FL1 | EMI_Filter_CommonMode | ‎445-LCV70-701-2PL-TL00CT-ND‎ (https://www.digikey.com/product-detail/en/LCV70-701-2PL-TL00/445-LCV70-701-2PL-TL00CT-ND/11682567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) |  | ~
31 | 1 | J1 | +5VD | Connector:Conn_01x02_Male |  | ~
32 | 2 | J2, J4 | in | dk_Coaxial-Connectors-RF:142-0701-801 | digikey-footprints:RF_SMA_BoardEdge_142-0701-801 | http://www.belfuse.com/resources/Johnson/drawings/dr-1420701801.pdf | Connectors, Interconnects | http://www.belfuse.com/resources/Johnson/drawings/dr-1420701801.pdf | /product-detail/en/cinch-connectivity-solutions-johnson/142-0701-801/J502-ND/35280 | CONN SMA JACK STR 50OHM EDGE MNT | J502-ND | Coaxial Connectors (RF) | 142-0701-801 | Cinch Connectivity Solutions Johnson | Active
33 | 2 | J3, J5 | out | dk_Coaxial-Connectors-RF:142-0701-801 | digikey-footprints:RF_SMA_BoardEdge_142-0701-801 | http://www.belfuse.com/resources/Johnson/drawings/dr-1420701801.pdf | Connectors, Interconnects | http://www.belfuse.com/resources/Johnson/drawings/dr-1420701801.pdf | /product-detail/en/cinch-connectivity-solutions-johnson/142-0701-801/J502-ND/35280 | CONN SMA JACK STR 50OHM EDGE MNT | J502-ND | Coaxial Connectors (RF) | 142-0701-801 | Cinch Connectivity Solutions Johnson | Active
34 | 1 | J6 | +5VA | Connector:Conn_01x02_Male |  | ~
35 | 1 | J7 | +3VA | Connector:Conn_01x02_Male |  | ~
36 | 1 | J8 | Antenna | dk_Coaxial-Connectors-RF:142-0701-801 | digikey-footprints:RF_SMA_BoardEdge_142-0701-801 | http://www.belfuse.com/resources/Johnson/drawings/dr-1420701801.pdf | Connectors, Interconnects | http://www.belfuse.com/resources/Johnson/drawings/dr-1420701801.pdf | /product-detail/en/cinch-connectivity-solutions-johnson/142-0701-801/J502-ND/35280 | CONN SMA JACK STR 50OHM EDGE MNT | J502-ND | Coaxial Connectors (RF) | 142-0701-801 | Cinch Connectivity Solutions Johnson | Active
37 | 1 | J9 | FREQ CTRL | Connector:Conn_01x06_Male |  | ~
38 | 1 | J10 | CLK_125MHz | Connector:Conn_01x02_Male |  | ~
39 | 1 | J11 | 50 Ohm IF IN | Connector:Conn_01x02_Male |  | ~
40 | 1 | JP1 | Vbias | Device:Jumper_NC_Dual |  | ~
41 | 1 | JP2 | Vparamp | Device:Jumper_NC_Dual |  | ~
42 | 1 | JP3 | paramp en | Jumper:SolderJumper_2_Open |  | ~
43 | 1 | JP4 | DDS Clock EN | Device:Jumper_NC_Dual |  | ~
44 | 1 | JP5 | Shift LO | Jumper:SolderJumper_3_Bridged12 |  | ~
45 | 1 | JP6 | A3 | Jumper:SolderJumper_2_Bridged |  | ~
46 | 2 | JP7, JP10 | choke bp | Jumper:SolderJumper_2_Open |  | ~
47 | 1 | JP8 | 5V LO | Jumper:SolderJumper_2_Open |  | ~
48 | 1 | JP9 | 3V LO | Jumper:SolderJumper_2_Bridged |  | ~
49 | 1 | JP11 | Jumper_NC_Dual | Device:Jumper_NC_Dual |  | ~
 | https://www.digikey.com/en/products/filter/fixed-inductors/71
50 | 4 | L1, L2, L10, L11 | 1.2u | ‎535-AISC-0603F-1R2J-TCT-ND‎ (https://www.digikey.com/product-detail/en/AISC-0603F-1R2J-T/535-AISC-0603F-1R2J-TCT-ND/4864670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) |  | ~
51 | 2 | L3, L14 | 19n | ‎490-14265-1-ND‎ (https://www.digikey.com/product-detail/en/LQW15CN20NJ1ZD/490-14265-1-ND/6221460?itemSeq=383415465) |  | ~
52 | 4 | L4, L12, L13 | 2.4n | ‎490-6797-1-ND‎ (https://www.digikey.com/product-detail/en/LQW15AN2N4C00D/490-6797-1-ND/3845994?itemSeq=383415679) |  | ~
53 | 2 | L5, L16 | 12n | ‎490-15102-1-ND‎ (https://www.digikey.com/product-detail/en/LQG15HS12NH02D/490-15102-1-ND/6799767?itemSeq=383415894) |  | ~
54 | 3 | L6, L23, L24 | 0.1u | ‎490-10538-1-ND‎ (https://www.digikey.com/product-detail/en/LQP03TG0N1B02D/490-10538-1-ND/5026482?itemSeq=383416010) |  | 0630CS
55 | 1 | L7 | 5u | ‎2184-BWLS001611094R7J00CT-ND‎ (https://www.digikey.com/product-detail/en/BWLS001611094R7J00/2184-BWLS001611094R7J00CT-ND/12141362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) |  | 0630CS
56 | 2 | L8, L9 | 56n | 490-15169-1-ND‎ (https://www.digikey.com/product-detail/en/LQG15HZ56NH02D/490-15169-1-ND/6799834?itemSeq=383416645) |  | ~
57 | 1 | L15 | 150nH | 445-180950-1-ND‎ (https://www.digikey.com/product-detail/en/MLJ1005WR15JT000/445-180950-1-ND/9565788?itemSeq=383433319) |  | 0630CS
58 | 2 | L17, L19 | 120n | ‎490-LQW15AWR12J80DCT-ND‎ (https://www.digikey.com/product-detail/en/LQW15AWR12J80D/490-LQW15AWR12J80DCT-ND/11690620?itemSeq=383433434) |  | ~
59 | 1 | L18 | 130n | 490-14279-1-ND‎ (https://www.digikey.com/product-detail/en/LQW15CNR13J0ZD/490-14279-1-ND/6221474?itemSeq=383433452) |  | ~
60 | 1 | L20 | 470n | LQW15CNR47J1ZD
61 | 2 | L21, L22 | 390n | ‎490-LQW15CAR39J00DCT-ND‎ (https://www.digikey.com/product-detail/en/LQW15CAR39J00D/490-LQW15CAR39J00DCT-ND/11690598?itemSeq=383433592)
62
63 | 1 | L25 | 33n | ‎2184-BWCS0012070733NG00CT-ND‎ (https://www.digikey.com/product-detail/en/BWCS0012070733NG00/2184-BWCS0012070733NG00CT-ND/10509441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) |  | ~
64 | 1 | L26 | 120n | ‎490-15867-1-ND‎ (https://www.digikey.com/product-detail/en/LQW18ASR12J0ZD/490-15867-1-ND/6800532?itemSeq=383433992) |  | ~
65 | 1 | L27 | 96n | ‎490-12081-1-ND‎ (https://www.digikey.com/product-detail/en/LQW15CN96NJ00D/490-12081-1-ND/5403066?itemSeq=383434255) |  | ~
66 | 1 | Q1 | MMBTH10 | Device:Q_NPN_BEC |  | ~
67 | 2 | Q2, Q3 | 2N2222 | Device:Q_NPN_BEC |  | ~
68 | 6 | R1, R2, R20, R23, R35, R37 | 1k | ‎13-RC0402FR-7W1KLCT-ND‎ (https://www.digikey.com/product-detail/en/RC0402FR-7W1KL/13-RC0402FR-7W1KLCT-ND/12699007?itemSeq=383438286) |  | ~
69 | 3 | R3, R4, R6 | 68k | ‎311-68.0KLRCT-ND‎ (https://www.digikey.com/product-detail/en/RC0402FR-0768KL/311-68.0KLRCT-ND/729598?itemSeq=383438377) |  | ~
70 | 2 | R5, R15 | 51 | ‎311-51.0LRCT-ND‎ (https://www.digikey.com/product-detail/en/RC0402FR-0751RL/311-51.0LRCT-ND/729576?itemSeq=383438427) |  | ~
71 | 1 | R7 | 47k | 311-47.0KLRCT-ND‎ (https://www.digikey.com/product-detail/en/RC0402FR-0747KL/311-47.0KLRCT-ND/729563?itemSeq=383438476) |  | ~
72 | 2 | R8, R9 | R |  |  | ~
73 | 1 | R10 | 470 | ‎311-470LRCT-ND‎ (https://www.digikey.com/product-detail/en/RC0402FR-07470RL/311-470LRCT-ND/729566?itemSeq=383439872) |  | ~
74 | 1 | R11 | 510 | ‎311-510LRCT-ND‎ (https://www.digikey.com/product-detail/en/RC0402FR-07510RL/311-510LRCT-ND/729579?itemSeq=383439957) |  | ~
75 | 1 | R12 | 68 | ‎311-68.0LRCT-ND‎ (https://www.digikey.com/product-detail/en/RC0402FR-0768RL/311-68.0LRCT-ND/729599?itemSeq=383440012) |  | ~
76 | 1 | R13 | 680 | ‎311-680LRCT-ND‎ (https://www.digikey.com/product-detail/en/RC0402FR-07680RL/311-680LRCT-ND/729601?itemSeq=383440078) |  | ~
77 | 1 | R14 | 100k | 311-100KLRCT-ND‎ (https://www.digikey.com/product-detail/en/RC0402FR-07100KL/311-100KLRCT-ND/729473?itemSeq=383443771) |  | ~
78 | 1 | R16 | 39k | 311-39.0KLRCT-ND‎ (https://www.digikey.com/product-detail/en/RC0402FR-0739KL/311-39.0KLRCT-ND/729548?itemSeq=383443614) |  | ~
79 | 2 | R17 | 0 | RC0402FR-070RL
80 | 1 | R18
81 | 1 | R19 |  |  | R3, R8
82 | 1 | R21 | 30 | ‎311-30.0HRCT-ND‎ (https://www.digikey.com/product-detail/en/RC0603FR-0730RL/311-30.0HRCT-ND/730086?itemSeq=383456774) |  | ~
83 | 2 | R22, R28 | 75 | ‎311-75.0HRCT-ND‎ (https://www.digikey.com/product-detail/en/RC0603FR-0775RL/311-75.0HRCT-ND/730324?itemSeq=383456789) |  | ~
84 | 1 | R24 | 150 | ‎311-150LRCT-ND‎ (https://www.digikey.com/product-detail/en/RC0402FR-07150RL/311-150LRCT-ND/729490?itemSeq=383456464) |  | ~
85 | 3 | R25, R27, R30 | 1.2k | ‎311-1.20KLRCT-ND‎ (https://www.digikey.com/product-detail/en/RC0402FR-071K2L/311-1.20KLRCT-ND/729464?itemSeq=383456510) |  | ~
86 | 1 | R26 | 2k | ‎311-2KLRCT-ND‎ (https://www.digikey.com/product-detail/en/RC0402FR-072KL/311-2KLRCT-ND/2827883?itemSeq=383456528)
87 | 1 | R29 | 3.9k | 311-3.90KLRCT-ND‎ (https://www.digikey.com/product-detail/en/RC0402FR-073K9L/311-3.90KLRCT-ND/729531?itemSeq=383456543)
88 | 2 | R31, R32 | 47 | ‎311-47.0LRCT-ND‎ (https://www.digikey.com/product-detail/en/RC0402FR-0747RL/311-47.0LRCT-ND/2827884?itemSeq=383456640)
89 | 2 | R33, R36 | 100 | ‎311-100LRCT-ND‎ (https://www.digikey.com/product-detail/en/RC0402FR-07100RL/311-100LRCT-ND/729474?itemSeq=383456573) |  | ~
90 | 1 | R34 | 10 | 311-100LRCT-ND‎ (https://www.digikey.com/product-detail/en/RC0402FR-07100RL/311-100LRCT-ND/729474?itemSeq=383456612) |  | ~
91 | 1 | T1 | Transformer_1P_1S | Device:Transformer_1P_1S |  | ~
92 | 1 | U1 | ADE-11X+ | dk_RF-Demodulators:ADE-11X+ | RF_Mini-Circuits:Mini-Circuits_CD542_LandPatternPL-052 | www.minicircuits.com/pdfs/ADE-6.pdf
93 | 1 | U2 | CMX901 | dk_RF-Amplifiers:CMX901 | Home:QFN-28_EP_5x5_Pitch0.5mm | CMX901QT8
94 | 1 | U3 | TXU0304RUTR | dk_Logic-Translators-Level-Shifters:TXU0304RUTR | Package_DFN_QFN:Texas_R_PUQFN-N12 | http://www.ti.com/lit/ds/symlink/txu0104.pdf
95 | 1 | U4 | AD9850 | Interface:AD9850 | Package_SO:SSOP-28_5.3x10.2mm_P0.65mm | https://www.analog.com/media/en/technical-documentation/data-sheets/AD9850.pdf
96 | 1 | U5 | SiT9365AC-2B1-33E | dk_Oscillators:SiT9365AC-2B1-33E | Home:POD-038-PQFD-006-C03225
97 | 1 | U6 | DS90LV028ATM | DS90LV028ATM:DS90LV028ATM | SOIC127P599X175-8N

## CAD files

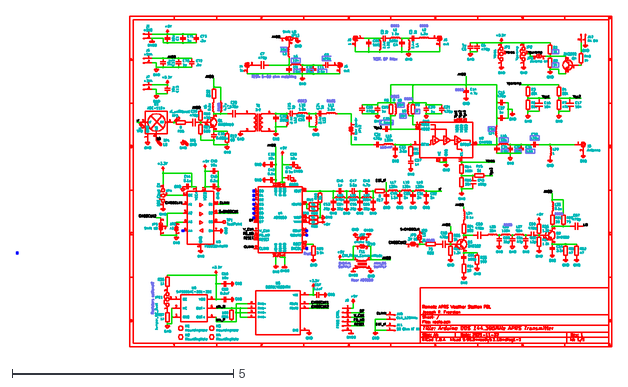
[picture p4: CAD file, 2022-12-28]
hardware/radio/radio.dxf
13.5 x 7.48

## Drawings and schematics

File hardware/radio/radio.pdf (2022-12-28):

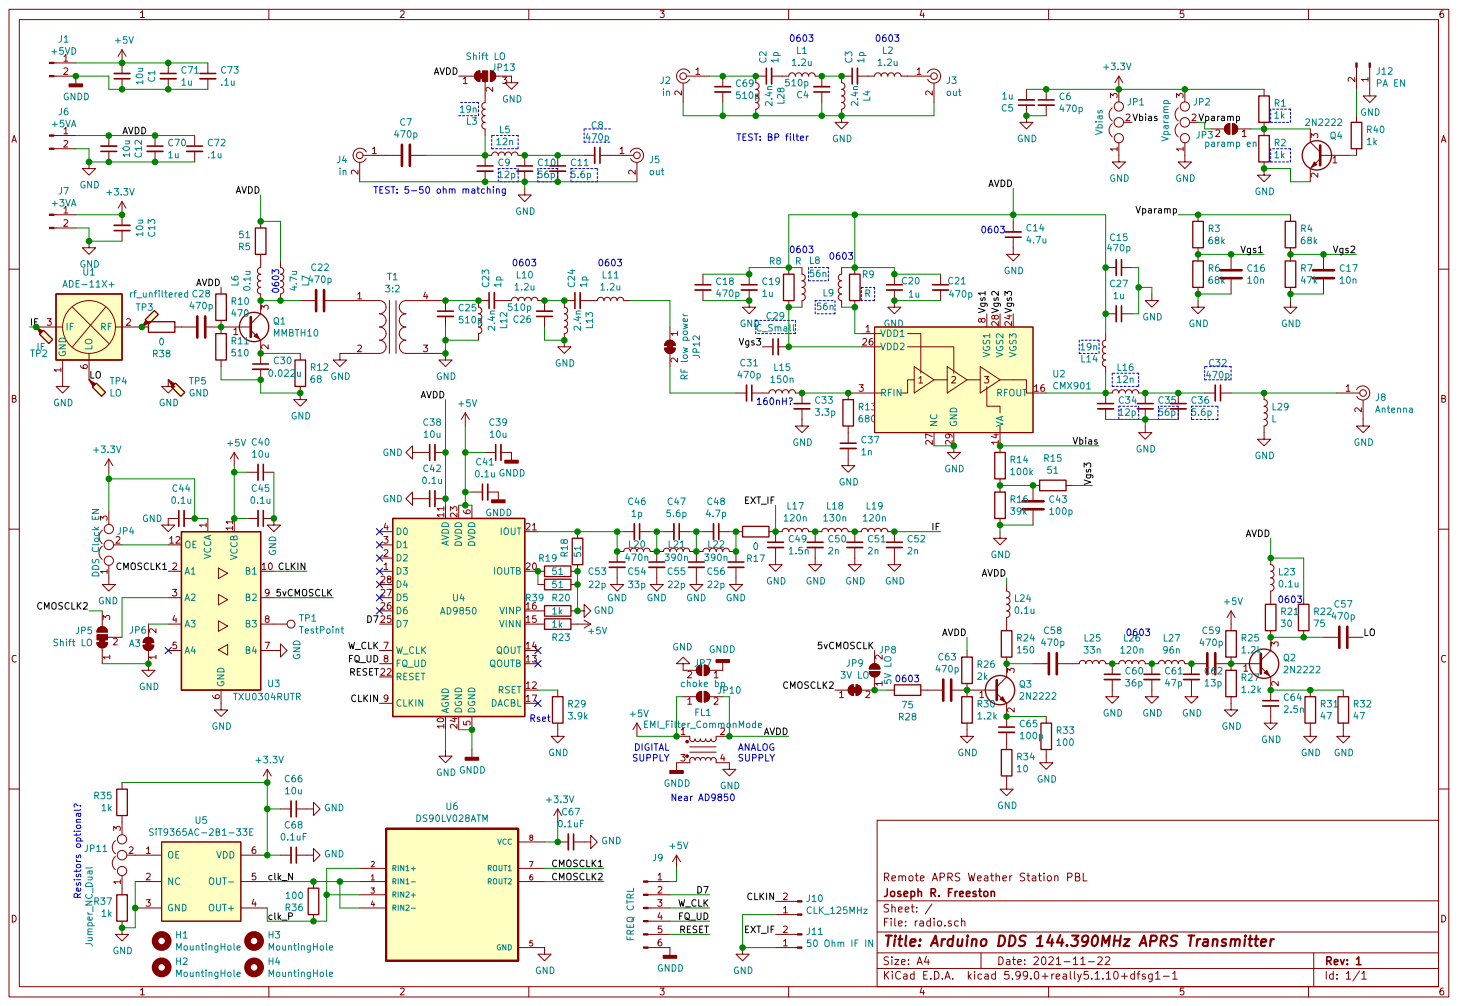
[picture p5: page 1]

3.9k GND
JP4 DDS Clock EN GND

Id: 1/1 Title: Arduino DDS 144.390MHz APRS Transmitter File: radio.sch Sheet: / Joseph R. Freeston Remote APRS Weather Station PBL

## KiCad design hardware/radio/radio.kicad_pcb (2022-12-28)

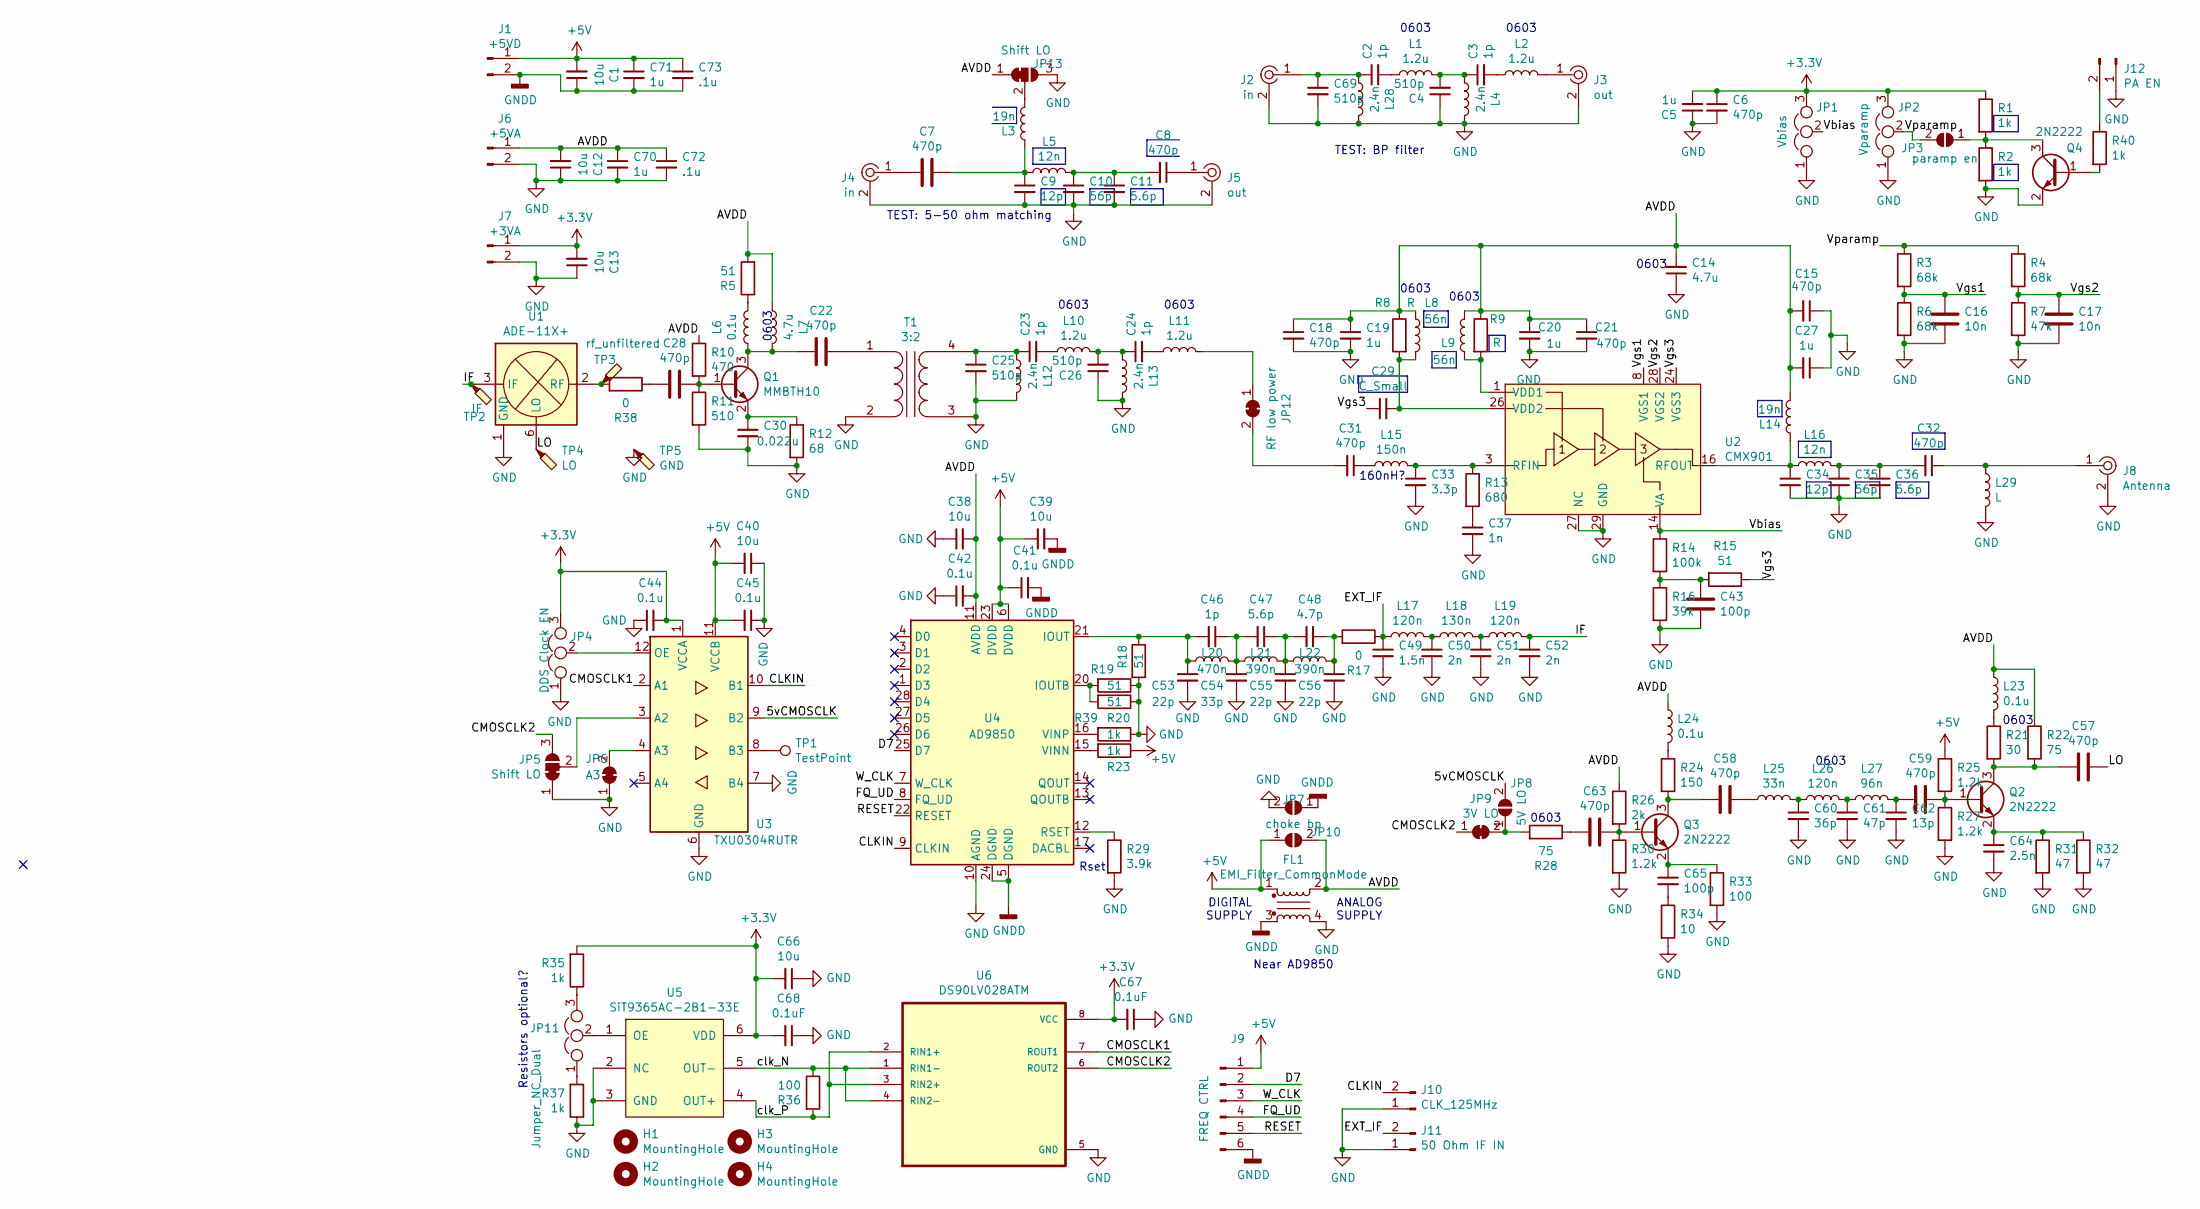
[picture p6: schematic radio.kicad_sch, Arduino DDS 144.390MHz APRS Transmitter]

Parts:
C1, C12, C13: 10u; C_0402_1005Metric
C2, C3, C23, C24, C46: 1p; C_0402_1005Metric
C4, C25, C26, C69: 510p; C_0402_1005Metric
C5, C19, C20, C27, C70, C71: 1u; C_0402_1005Metric
C6, C7, C8, C15, C18, C21, C22, C28, C31, C32, C57, C58, C59, C63: 470p; C_0402_1005Metric
C9, C34: 12p; C_0402_1005Metric
C10, C35: 56p; C_0402_1005Metric
C11, C36, C47: 5.6p; C_0402_1005Metric
C14: 4.7u; C_0603_1608Metric
C16, C17: 10n; C_0402_1005Metric
C29: C_Small; C_0402_1005Metric
C30: 0.022u; C_0402_1005Metric
C33: 3.3p; C_0402_1005Metric
C37: 1n; C_0402_1005Metric
C38, C39, C40, C66: 10u; C_0603_1608Metric
C41, C42, C44, C45: 0.1u; C_0402_1005Metric
C43, C65: 100p; C_0402_1005Metric
C48: 4.7p; C_0402_1005Metric
C49: 1.5n; C_0402_1005Metric
C50, C51, C52: 2n; C_0402_1005Metric
C53, C55, C56: 22p; C_0402_1005Metric
C54: 33p; C_0402_1005Metric
C60: 36p; C_0402_1005Metric
C61: 47p; C_0402_1005Metric
C62: 13p; C_0402_1005Metric
C64: 2.5n; C_0402_1005Metric
C67, C68: 0.1uF; C_0402_1005Metric
C72, C73: .1u; C_0402_1005Metric
FL1: EMI_Filter_CommonMode; common_mode_choke
H1, H2, H3, H4: MountingHole; MountingHole_3mm
J1: +5VD; PinHeader_1x02_P2.54mm_Vertical
J2, J4: in; RF_SMA_BoardEdge_142-0701-801; MPN 142-0701-801; Digi-Key_PN J502-ND
J3, J5: out; RF_SMA_BoardEdge_142-0701-801; MPN 142-0701-801; Digi-Key_PN J502-ND
J6: +5VA; PinHeader_1x02_P2.54mm_Vertical
J7: +3VA; PinHeader_1x02_P2.54mm_Vertical
J8: Antenna; RF_SMA_BoardEdge_142-0701-801; MPN 142-0701-801; Digi-Key_PN J502-ND
J9: FREQ CTRL; PinHeader_1x06_P2.54mm_Vertical
J10: CLK_125MHz; PinHeader_1x02_P2.54mm_Vertical
J11: 50 Ohm IF IN; PinHeader_1x02_P2.54mm_Vertical
J12: PA EN; PinHeader_1x02_P2.54mm_Vertical
JP1: Vbias; PinHeader_1x03_P2.54mm_Vertical
JP2: Vparamp; PinHeader_1x03_P2.54mm_Vertical
JP3: paramp en; SolderJumper-2_P1.3mm_Open_RoundedPad1.0x1.5mm
JP4: DDS Clock EN; PinHeader_1x03_P2.54mm_Vertical
JP5, JP13: Shift LO; SolderJumper-3_P1.3mm_Bridged2Bar12_Pad1.0x1.5mm
JP6: A3; SolderJumper-2_P1.3mm_Bridged2Bar_Pad1.0x1.5mm
JP7, JP10: choke bp; SolderJumper-2_P1.3mm_Open_Pad1.0x1.5mm
JP8: 5V LO; SolderJumper-2_P1.3mm_Open_Pad1.0x1.5mm
JP9: 3V LO; SolderJumper-2_P1.3mm_Bridged2Bar_Pad1.0x1.5mm
JP11: Jumper_NC_Dual; PinHeader_1x03_P2.54mm_Vertical
JP12: RF low power; SolderJumper-2_P1.3mm_Bridged2Bar_Pad1.0x1.5mm
L1, L2, L10, L11: 1.2u; L_0603_1608Metric
L3, L14: 19n; L_0402_1005Metric
L4, L12, L13, L28: 2.4n; L_0402_1005Metric
L5, L16: 12n; L_0402_1005Metric
L6, L23, L24: 0.1u; L_0402_1005Metric
L7: 4.7u; L_0603_1608Metric
L8, L9: 56n; L_0603_1608Metric
L15: 150n; L_0402_1005Metric
L17, L19: 120n; L_0402_1005Metric
L18: 130n; L_0402_1005Metric
L20: 470n; L_0402_1005Metric
L21, L22: 390n; L_0402_1005Metric
L25: 33n; L_0402_1005Metric
L26: 120n; L_0603_1608Metric
L27: 96n; L_0402_1005Metric
L29: L; L_0805_2012Metric
Q1: MMBTH10; SOT-23
Q2, Q3, Q4: 2N2222; SOT-23
R1, R2, R20, R23, R35, R37, R40: 1k; R_0402_1005Metric
R3, R4, R6: 68k; R_0402_1005Metric
R5, R15, R18, R19, R39: 51; R_0402_1005Metric
R7: 47k; R_0402_1005Metric
R8, R9: R; R_0402_1005Metric
R10: 470; R_0402_1005Metric
R11: 510; R_0402_1005Metric
R12: 68; R_0402_1005Metric
R13: 680; R_0402_1005Metric
R14: 100k; R_0402_1005Metric
R16: 39k; R_0402_1005Metric
R17, R38: 0; R_0402_1005Metric
R21: 30; R_0603_1608Metric
R22, R28: 75; R_0603_1608Metric
R24: 150; R_0402_1005Metric
R25, R27, R30: 1.2k; R_0402_1005Metric
R26: 2k; R_0402_1005Metric
R29: 3.9k; R_0402_1005Metric
R31, R32: 47; R_0402_1005Metric
R33, R36: 100; R_0402_1005Metric
R34: 10; R_0402_1005Metric
T1: 3:2; Transformer_Toroid_Horizontal_D9.0mm_Amidon-T30
TP1: TestPoint; TestPoint_Pad_2.0x2.0mm
TP2: IF; TestPoint_Pad_2.0x2.0mm
TP3: rf_unfiltered; TestPoint_Pad_2.0x2.0mm
TP4: LO; TestPoint_Pad_2.0x2.0mm
TP5: GND; TestPoint_Pad_2.0x2.0mm
U1: ADE-11X+; Mini-Circuits_CD542_LandPatternPL-052
U2: CMX901; QFN-28_EP_5x5_Pitch0.5mm
U3: TXU0304RUTR; Texas_R_PUQFN-N12
U4: AD9850; SSOP-28_5.3x10.2mm_P0.65mm
U5: SiT9365AC-2B1-33E; POD-038-PQFD-006-C03225
U6: DS90LV028ATM; SOIC127P599X175-8N

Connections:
+3V3: C5.2, C6.1, C13.2, C44.2, C66.2, C67.2, C68.2, J7.1, JP1.3, JP2.3, JP4.3, R1.1, R35.2, U3.1 (VCCA), U5.6 (VDD), U6.8 (VCC)
+5V: C1.2, C39.1, C40.2, C41.1, C45.2, C71.1, C73.1, FL1.1, J1.1, J9.1, JP10.1 (A), R23.1, R25.1, U3.11 (VCCB), U4.6 (DVDD), U4.23 (DVDD)
/5vCMOSCLK: JP8.2 (B), U3.9 (B2)
/AVDD: C12.2, C14.2, C15.2, C18.1, C19.1, C20.1, C21.1, C27.2, C38.2, C42.2, C70.1, C72.1, FL1.2, J6.1, JP10.2 (B), JP13.1 (A), L7.1, L8.2, L9.2, L14.2, L23.1, L24.1, R5.2, R8.1, R9.1, R10.1, R22.1, R26.1, U4.11 (AVDD), U4.18 (AVDD)
/CLKIN: J10.2, U3.10 (B1), U4.9 (CLKIN)
/CMOSCLK1: U3.2 (A1), U6.7 (ROUT1)
/CMOSCLK2: JP5.3 (B), JP9.1 (A), U6.6 (ROUT2)
/D7: J9.2, U4.25 (D7)
/EXT_IF: C49.1, J11.2, L17.1, R17.1
/FQ_UD: J9.4, U4.8 (FQ_UD)
/IF: C52.1, L19.2, TP2.1, U1.3 (IF)
/LO: C57.1, TP4.1, U1.6 (LO)
/RESET: J9.5, U4.22 (RESET)
/Vbias: JP1.2, R14.1, U2.14 (VA)
/Vgs1: C16.1, R3.2, R6.1, U2.8 (VGS1)
/Vgs2: C17.1, R4.2, R7.1, U2.28 (VGS2)
/Vgs3: C29.1, R15.1, U2.24 (VGS3)
/Vparamp: JP2.2, JP3.2 (B), R3.1, R4.1
/W_CLK: J9.3, U4.7 (W_CLK)
/clk_N: R36.1, U5.5 (OUT-), U6.1 (RIN1-), U6.4 (RIN2-)
/clk_P: R36.2, U5.4 (OUT+), U6.2 (RIN1+), U6.3 (RIN2+)
GND: C4.1, C5.1, C6.2, C9.2, C10.2, C11.2, C12.1, C13.1, C14.1, C15.1, C16.2, C17.2, C18.2, C19.2, C20.2, C21.2, C25.2, C26.1, C27.1, C30.2, C33.2, C34.2, C35.2, C36.2, C37.2, C38.1, C40.1, C42.1, C43.2, C44.1, C45.1, C49.2, C50.2, C51.2, C52.2, C53.2, C54.2, C55.2, C56.2, C60.2, C61.2, C62.2, C64.2, C66.1, C67.1, C68.1, C69.2, C70.2, C72.2, FL1.4, J2.2, J3.2, J4.2, J5.2, J6.2, J7.2, J8.2, J10.1, J11.1, J12.1, JP1.1, JP2.1, JP4.1, JP5.1 (A), JP6.1 (A), JP7.2 (B), JP13.3 (B), L4.2, L12.2, L13.2, L28.2, L29.2, Q4.2 (E), R2.2, R6.2, R7.2, R11.2, R12.2, R16.2, R18.2, R19.1, R20.1, R27.2, R29.2, R30.2, R31.2, R32.2, R33.2, R34.2, R37.1, R39.1, T1.2 (AB), T1.3 (SA), TP5.1, U1.1 (GND), U1.4 (GND), U1.5 (GND), U2.2 (NC), U2.4 (NC), U2.6 (NC), U2.7 (NC), U2.9 (NC), U2.10 (NC), U2.11 (NC), U2.12 (NC), U2.13 (NC), U2.15 (NC), U2.21 (NC), U2.22 (NC), U2.23 (NC), U2.25 (NC), U2.27 (NC), U2.29 (GND), U3.6 (GND), U3.7 (B4), U4.10 (AGND), U4.19 (AGND), U5.2 (NC), U5.3 (GND), U6.5 (GND)
GNDD: C1.1, C39.2, C41.2, C71.2, C73.2, FL1.3, J1.2, J9.6, JP7.1 (A), U4.5 (DGND), U4.24 (DGND)
unnamed: C2.1, C69.1, J2.1, L28.1
unnamed: C2.2, L1.1
unnamed: C3.1, C4.2, L1.2, L4.1
unnamed: C3.2, L2.1
unnamed: C7.1, C9.1, L3.1, L5.1
unnamed: C7.2, J4.1
unnamed: C8.1, J5.1
unnamed: C8.2, C10.1, C11.1, L5.2
unnamed: C22.1, T1.1 (AA)
unnamed: C22.2, L6.1, L7.2, Q1.3 (C)
unnamed: C23.1, C25.1, L12.1, T1.4 (SB)
unnamed: C23.2, L10.1
unnamed: C24.1, C26.2, L10.2, L13.1
unnamed: C24.2, L11.1
unnamed: C28.1, Q1.1 (B), R10.2, R11.1
unnamed: C28.2, R38.1
unnamed: C29.2, L8.1, R8.2, U2.26 (VDD2)
unnamed: C30.1, Q1.2 (E), R12.1
unnamed: C31.1, L15.1
unnamed: C31.2, JP12.2 (B)
unnamed: C32.1, J8.1, L29.1
unnamed: C32.2, C35.1, C36.1, L16.2
unnamed: C33.1, L15.2, R13.1, U2.3 (RFIN), U2.5 (RFIN)
unnamed: C34.1, L14.1, L16.1, U2.16 (RFOUT), U2.17 (RFOUT), U2.18 (RFOUT), U2.19 (RFOUT), U2.20 (RFOUT)
unnamed: C37.1, R13.2
unnamed: C43.1, R14.2, R15.2, R16.1
unnamed: C46.1, C47.2, C54.1, L20.2, L21.1
unnamed: C46.2, C53.1, L20.1, R18.1, U4.21 (IOUT)
unnamed: C47.1, C48.2, C55.1, L21.2, L22.1
unnamed: C48.1, C56.1, L22.2, R17.2
unnamed: C50.1, L17.2, L18.1
unnamed: C51.1, L18.2, L19.1
unnamed: C57.2, Q2.3 (C), R21.2, R22.2
unnamed: C58.1, L25.1
unnamed: C58.2, Q3.3 (C), R24.2
unnamed: C59.1, Q2.1 (B), R25.2, R27.1
unnamed: C59.2, C62.1, L27.2
unnamed: C60.1, L25.2, L26.1
unnamed: C61.1, L26.2, L27.1
unnamed: C63.1, Q3.1 (B), R26.2, R30.1
unnamed: C63.2, R28.1
unnamed: C64.1, Q2.2 (E), R31.1, R32.1
unnamed: C65.1, Q3.2 (E), R33.1
unnamed: C65.2, R34.1
unnamed: J3.1, L2.2
unnamed: J12.2, R40.1
unnamed: JP3.1 (A), Q4.3 (C), R1.2, R2.1
unnamed: JP4.2, U3.12 (OE)
unnamed: JP5.2 (C), U3.3 (A2)
unnamed: JP6.2 (B), U3.4 (A3)
unnamed: JP8.1 (A), JP9.2 (B), R28.2
unnamed: JP11.1, R37.2
unnamed: JP11.2, U5.1 (OE)
unnamed: JP11.3, R35.1
unnamed: JP12.1 (A), L11.2
unnamed: JP13.2 (C), L3.2
unnamed: L6.2, R5.1
unnamed: L9.1, R9.2, U2.1 (VDD1)
unnamed: L23.2, R21.1
unnamed: L24.2, R24.1
unnamed: Q4.1 (B), R40.2
unnamed: R19.2, R39.2, U4.20 (IOUTB)
unnamed: R20.2, U4.16 (VINP)
unnamed: R23.2, U4.15 (VINN)
unnamed: R29.1, U4.12 (RSET)
unnamed: R38.2, TP3.1, U1.2 (RF)
unnamed: TP1.1, U3.8 (B3)

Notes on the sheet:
0603
TEST: 5-50 ohm matching
Near AD9850
DIGITAL SUPPLY
Rset
0603
TEST: BP filter
ANALOG SUPPLY
160nH?
Resistors optional?

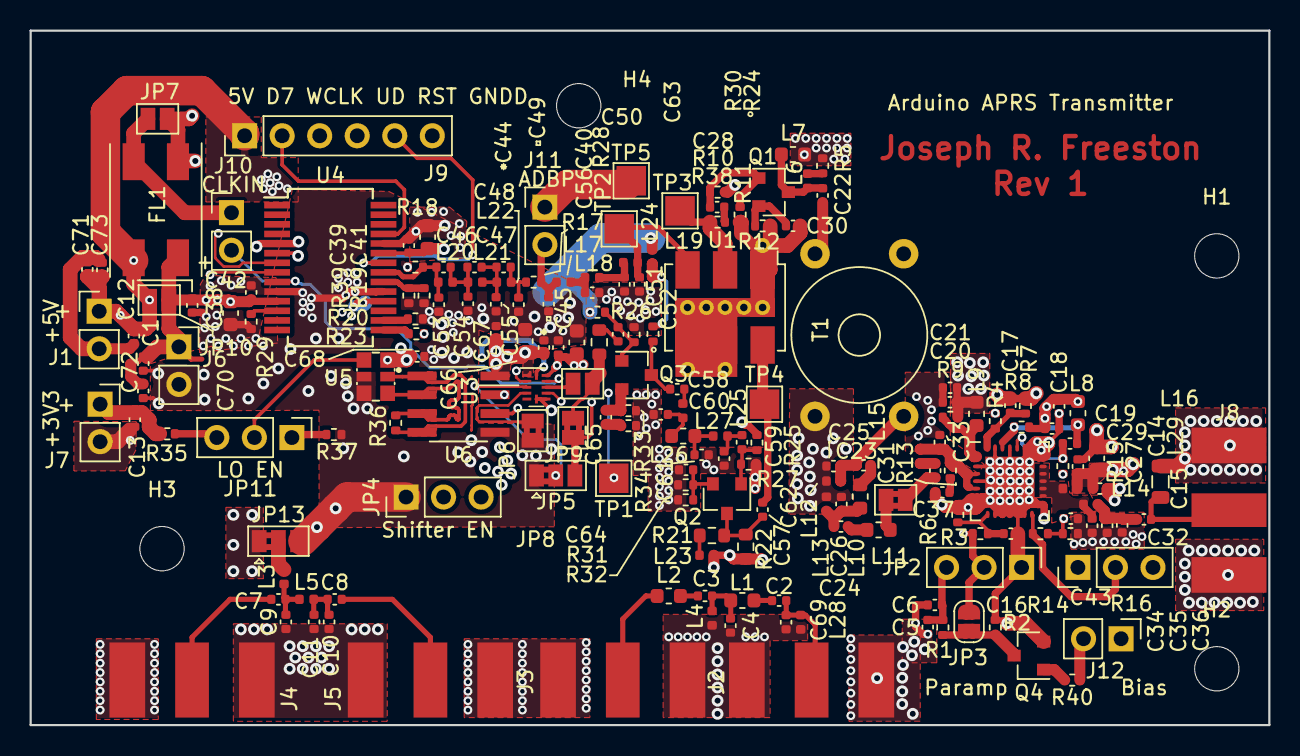
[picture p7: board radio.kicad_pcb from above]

Board: 4 copper layers, 83.8 x 47.0 mm, 188 parts (0 on the bottom side), 90 nets.

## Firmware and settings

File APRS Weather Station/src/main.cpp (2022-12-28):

#include <Arduino.h>
#include <AD9850SPI.h>
#include <SPI.h>
#include <string.h>

const int W_CLK_PIN = 13;
const int FQ_UD_PIN = 4;
const int RESET_PIN = 5;

double freq = 1000000;
double trimFreq = 124999500;

int phase = 0;

const byte maxChars = 32;
char receivedChars[maxChars];   // an array to store the received data

void printParams(void);
bool recCommand(void);

void setup(){
  Serial.begin(9600);
  DDS.begin(W_CLK_PIN, FQ_UD_PIN, RESET_PIN);
  DDS.calibrate(trimFreq);
  DDS.setfreq(freq, phase);
  Serial.println("+-------------------------+");
  Serial.println("|   AD9850 Test Program   |");
  Serial.println("| Joseph R. Freeston 2022 |");
  Serial.println("+-------------------------+");
  Serial.println();
  printParams();
  Serial.println();
  Serial.println();
  Serial.println("Enter a command.");
  Serial.println("Begin with either R, F, U, P, or D and an optional float following the first character.");
  Serial.print(">>> ");

}

void loop(){
  if(recCommand()) {
    if(receivedChars[0] == 'F') {         // Set frequency
      freq = atof(&receivedChars[1]);
      DDS.setfreq(freq, phase);
    } else if(receivedChars[0] == 'R') {  // Set reference
      trimFreq = atof(&receivedChars[1]);
      DDS.calibrate(trimFreq);
    } else if(receivedChars[0] == 'P') {  // Set phase
      phase = atof(&receivedChars[1]);
      DDS.setfreq(freq, phase);
    } else if(receivedChars[0] == 'U') {  // Up
      DDS.up();
    } else if(receivedChars[0] == 'D') {  // Down
      DDS.down();
    } else {
      Serial.println("Invalid command. Begin with either R, F, U, P, or D and an optional float following the first character.");
    }
    printParams();
    Serial.print("\n>>> ");
  }
}

void printParams() {
  Serial.println("------------------------------");
  Serial.print("Reference set to ");
  Serial.print(trimFreq, DEC);
  Serial.println("Hz");
  Serial.print("Frequency set to ");
  Serial.print(freq, DEC);
  Serial.println("Hz");
  Serial.print("Phase set to ");
  Serial.print(phase*11.25, DEC);
  Serial.println("°");
  Serial.println("------------------------------");
}

bool recCommand() {
  static byte i = 0;
  const char endMarker = '\n';
  char rc;

  while (Serial.available() > 0) {
    rc = Serial.read();
    Serial.write(rc);

    if(rc != endMarker) {
      receivedChars[i] = rc;
      if(i < maxChars) i++;
    } else {
      receivedChars[i] = '\0';
      i = 0;
      return true;
    }
  }
  return false;
}
